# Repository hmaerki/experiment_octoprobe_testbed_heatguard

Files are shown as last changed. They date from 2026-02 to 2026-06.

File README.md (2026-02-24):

# experiment_octoprobe_testbed_heatguard
Use octoprobe to test the heatguard for vat pasteurization

## Punchy names for the subsystem

If you want a single, punchy name that sounds professional and captures the "guardian" nature of the device, here are a few proposals categorized by their "vibe":

The Technical Favorites
These sound like official components you would find in an industrial manual:

Thermostop: Clear, concise, and tells you exactly what happens when things go wrong.

Heatguard: Suggests a protective layer standing between the tank and a meltdown.

Safeterm: A portmanteau of "Safety" and "Thermal."

Sentitherm: Combines "Sentinel" (a guard) and "Thermal."

The "Action" Names
These focus on the emergency intervention aspect:

Interlock: The classic engineering term for a system that prevents operation unless specific safety conditions are met.

Cutout: Simple and direct; it describes the physical act of breaking the circuit.

Failsafe: Implies the system is designed to default to a safe state (off) upon error.

The Modern/Sleek Options
If you are naming this for a software module or a branded product:

Pyrowatch: Sounds vigilant and high-tech.

Calyx: (The protective outer part of a flower) — a bit more abstract, but sophisticated.

Vigilant: Short, evocative, and emphasizes the monitoring aspect.

## Punchy names for the application

* Industry	The Problem	The Punchy Name
* Aerospace	Engine overheating	AeroFailsafe
* Nuclear/Energy	Reactor/Boiler runaway	CoreWatch
* Home Automation	Smart water heaters	HomeSentry
* Cryogenics	Warming of liquid nitrogen	FrostGuard

## Industries

1. The Pharmaceutical Industry

In drug manufacturing, "stable" isn't good enough—it must be exact.

* The Application: Water is used in Jacketed Reactors to maintain precise environments for chemical synthesis and in Autoclaves for sterilization.
* The Precision: Often requires accuracy within $\pm 0.5$°C.
* The Risk: If the sensor drifts, the "active pharmaceutical ingredients" (APIs) can degrade, rendering a multi-million dollar batch useless or toxic.
* TPC Punchy Name: BatchGuard2.

2. Food & Beverage (Pasteurization)

Any process involving the "Kill Stage" for bacteria requires a TPC to ensure the temperature never dips too low or spikes too high.

* The Application: Flash Pasteurization of milk, juices, or beer.The Precision: Liquids must be held at a specific temperature (e.g., $72$°C) for a precise number of seconds.
* The Risk: Too low, and you risk a Salmonella outbreak; too high, and the product "cooks" or denatures, ruining the flavor.TPC Punchy Name: PureFlow3. Semiconductor & Electronics ManufacturingThe machines that make computer chips (Photolithography) require incredibly stable thermal environments.
* The Application: Deionized (DI) Water Heating for cleaning silicon wafers.
* The Precision: Thermal fluctuations can cause microscopic expansion or contraction of the wafers, leading to alignment errors in the nanometer range.
* The Risk: Total loss of "yield" (the number of working chips per wafer).
* TPC Punchy Name: NanoSentry

4. Textile & Chemical Dyeing

Color consistency in high-end textiles depends entirely on the temperature of the water bath.

* The Application: Industrial Dye Vats.
* The Precision: Dyes react differently at $79$°C than at $82$°C, causing "color banding."
* The Risk: "Metamerism" (where the color looks different under different lights) or uneven coloring across thousands of meters of fabric.
* TPC Punchy Name: HueLock

5. Modern District Heating (Smart Cities)

Centralized boilers that pump hot water to entire neighborhoods.

* The Application: Hydronic Balancing of large-scale heating loops.
* The Precision: Modern systems use "Predictive Temperature Control" to adjust water heat based on outdoor weather.
* The Risk: A sensor error could lead to "Scald Events" in residential taps or massive energy waste if the boiler over-fires.
* TPC Punchy Name: CitySentry

## Real world products

* https://www.cstainlessllc.com/files/pdfs/vat-pasteurizer-brochure.pdf
* https://www.ancoequipment.com/batch-pasteurizers
* https://pmc.ncbi.nlm.nih.gov/articles/PMC12026572/
  * https://pmc.ncbi.nlm.nih.gov/articles/PMC12026572/table/foods-14-01342-t001/
* https://kalt-ag.ch/en/cheese-vats/
* https://inoxmontagen.ch/produkte/kaesekessel-und-pasteurisatoren/pasteurisator-plevnik-alles-in-einem/
* https://inoxmontagen.ch/produkte/kaesekessel-und-pasteurisatoren/pasteurisatoren-pasteur-plevnik/
* https://www.gea.com/en/products/liquid-processing/pasteurizers/milk-pasteurizer/

## Diagrams about UHT

https://asutp.org/Tetra_Pak/Dairy-Processing-Handbook-Tetrapak.pdf

  * UHT treatment

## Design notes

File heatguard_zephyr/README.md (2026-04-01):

# devcontainer

```bash
west init .
west update --narrow --fetch-opt=--depth=1
west build -b rpi_pico heatguard_zephyr
```

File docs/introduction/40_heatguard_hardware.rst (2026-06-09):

Heatguard Hardware
===========================

:download:`Schematics v0.3 (Pdf) <../../kicad/heatguard_v0.3/production_v0.3/schematics_heatguard_v0.3.pdf>`.

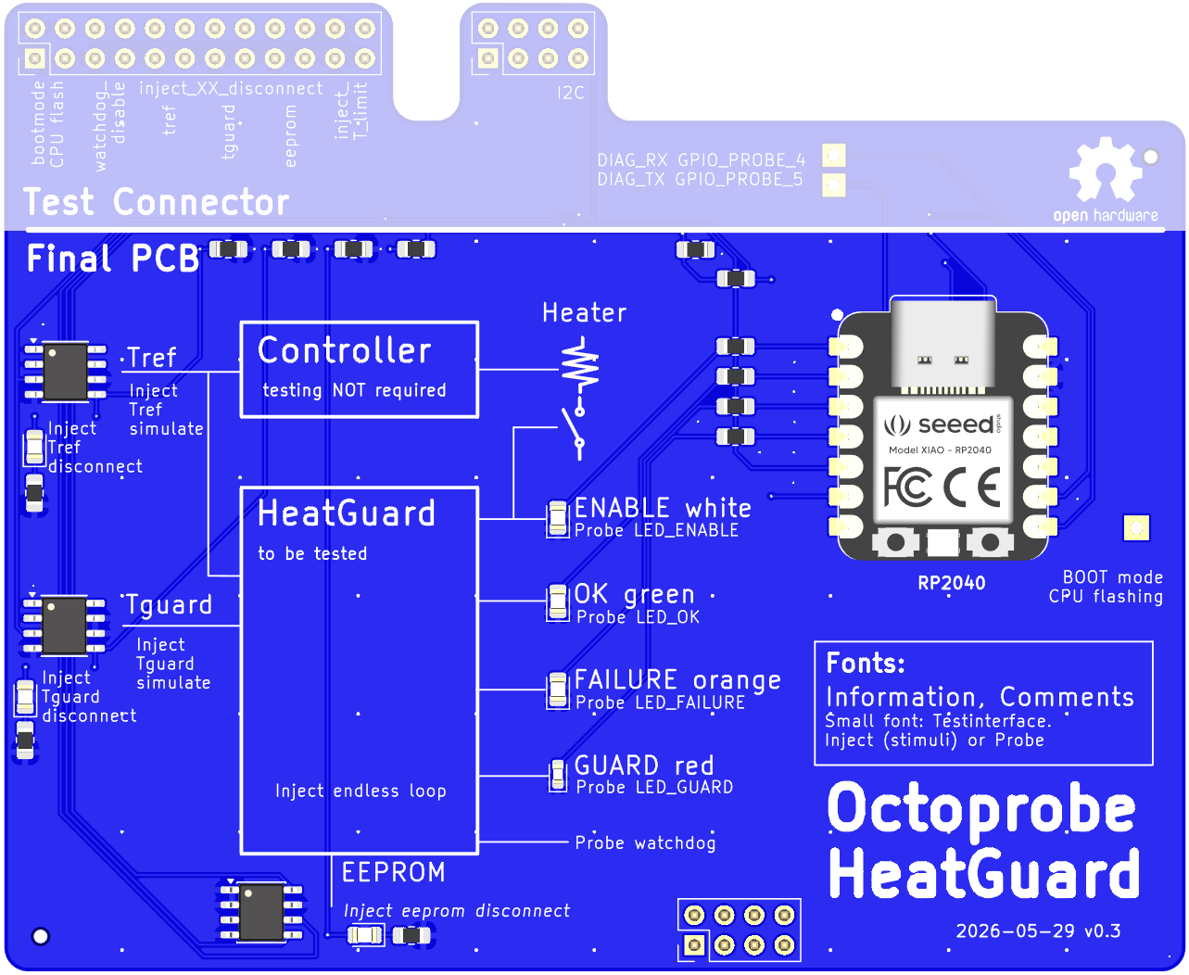
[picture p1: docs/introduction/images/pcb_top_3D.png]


To understand the hardware, just look at the silkscreen carefully. Note that I used a small fonts to describe what was added for the testinterface.

.. note:: 

  The implementation of the `Stimuly (inject)` and `Probes` only has very minimal impact on the `Final PCB`: We do not want to make the final PCB more expensive or bigger!

  The `Test Connector` would be typically implemented using flying probes or a solder pads as this requires minimal space on the PCB and no additional cost.

Assignements of the 8 pin testconnector and the relays
--------------------------------------------------------

.. list-table::
   :header-rows: 1

   * - Tentacle
     - DUT - heatguard
     - Signal
   * - relay 1
     - Boot button
     - Boot mode
   * - relay 2
     - pin 10, gpio 4
     - watchdog_disable
   * - relay 3
     - \-
     - inject_Tref_disconnect
   * - relay 4
     - \-
     - inject_Tguard_disconnect
   * - relay 5 
     - \-
     - inject_EEPROM_disconnect
   * - relay 6
     - pin 9, gpio 2
     - inject_T_limit (overwrite Tguard over temperature output)
   * - gpio 12
     - pin 5, gpio 6
     - SDA
   * - gpio 13
     - pin 6, gpio 7
     - SCL
   * - GPIO_PROBE_4
     - pin 8, gpio 1
     - DIAG_RX
   * - GPIO_PROBE_5
     - pin 7, gpio 0
     - DIAG_TX

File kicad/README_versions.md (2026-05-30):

# Octoprobe Heatguard

## History v0.2 -> v0.3

* PCB/Schematics: Now using relays in favor of GPIO
* PCB/Schematics: Rename stimuly -> stimulus
* PCB silkscreen: Open Hardware logo
* PCB silkscreen: Insert missing text `Controller` / `testing not required`
* PCB silkscreen: Switch GPIO_PROBE_4 and GPIO_PROBE_4
* PCB: XIAO rp2040: Replace SMD with THT

## History v0.1 -> v0.2

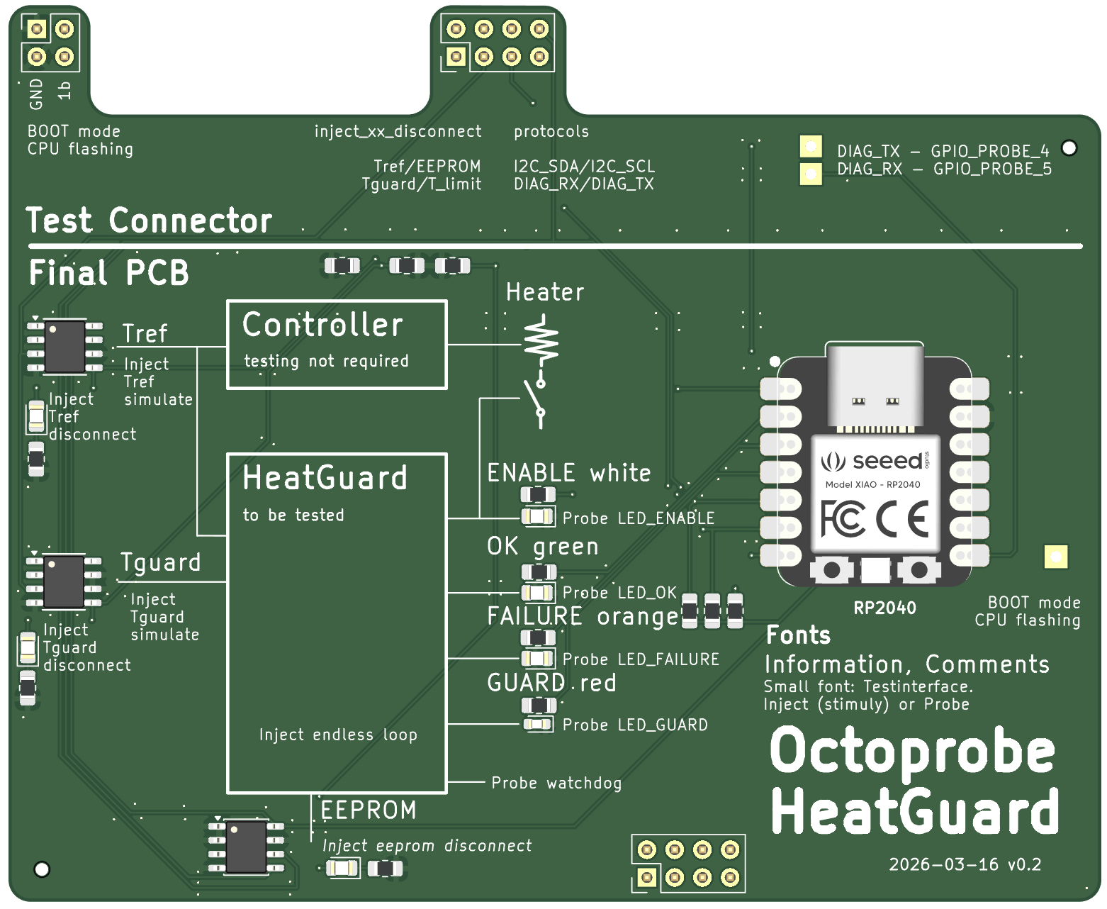
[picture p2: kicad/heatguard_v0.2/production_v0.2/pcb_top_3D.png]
tentacle


[schematics](heatguard_v0.2/production_v0.2/schematics_heatguard_v0.2.pdf)

* XIAO: Now smd (was on pins)
* Now connect to tentacle via soldered 2 row pin connectors
* while LEDs for inject Tref/Tguard/EEPROM

## History v0.1

tentacle

[schematics](heatguard_v0.1/production_v0.1/schematics_heatguard_v0.1.pdf)

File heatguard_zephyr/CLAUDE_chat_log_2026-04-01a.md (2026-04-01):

# Chat Log 2026-04-01a — Heatguard Zephyr Port

## Request 1: Add a Claude specification/hints file

Created `/CLAUDE.md` at the project root with hints covering:
- Project purpose (Octoprobe HIL test environment for heatguard)
- Python ≥ 3.12, `.venv/`, `uv pip install`
- Lint/type-check/test commands (ruff, mypy strict, pylint, pytest)
- Code style (ruff target py312, E501 disabled, mypy strict, PEP 561)
- Project layout (`src/`, `tests/`, `docs/`, `commissioning/`, `kicad/`, `heatguard_zephyr/`)
- Key conventions (PDM backend, octoprobe dependency, test markers)

## Request 2: Follow the instructions in `heatguard_zephyr/CLAUDE.md`

The file `heatguard_zephyr/CLAUDE.md` instructed:

> This folder contains a zephyr application which runs on a Raspberry Pi Pico.
> The program is already implemented in micropython, see `./main.py`.
> This program should now be rewritten in C/C++ to run on zephyr.
>
> Required Results:
> - Directory structure as used for a common zephyr application.
> - Script which compiles the sources into the firmware using `ghcr.io/zephyrproject-rtos/zephyr-build:main`.

### Files created

```
heatguard_zephyr/
  west.yml                     # West manifest (zephyr + hal_rpi_pico + picolibc)
  CMakeLists.txt               # Zephyr CMake build file
  prj.conf                     # Kconfig: GPIO, I2C, UART, WDT, float printf
  build.sh                     # Docker build script (zephyr-build:main)
  boards/
    rpi_pico.overlay           # DT overlay: I2C1 GPIO6/7, UART0 9600 baud
  src/
    main.c                     # Full C port of main.py
```

### Port details

- **State machine** — `INIT → OK → FAILURE / GUARD` with same thresholds:
  - 80 °C guard trigger
  - 3 °C diff failure trigger
  - 60 s guard recovery timeout
- **Diagnostic UART** — parses the same commands:
  - `stimulus heatguard.update_temperatures(temperature_Tguard_C=…, diff_C=…)`
  - `stimulus heatguard.sensor_failed("…")`
  - `inject timeover`
  - `inject endless_loop`
  - `ping` → `pong 'response to ping'`
- **I2C** — raw register reads for LM75B (11-bit temperature) and AT24C02 EEPROM
- **Boot cause** — Zephyr `hwinfo` API → `PWRON_RESET` / `WDT_RESET`
- **LEDs** — GPIO26-29 status LEDs, GPIO16/17/25 XIAO onboard (active-low)
- **Watchdog** — 3 s hardware WDT via Zephyr WDT API
- **Build** — `./build.sh` runs Docker, outputs `zephyr.uf2` + `zephyr.elf`

### Bug note

The Python `sensor_failed()` had `self.state == (self.STATE_INIT, self.STATE_GUARD)` which always evaluates `False` (comparing a string to a tuple). The C port uses the likely intended `state == STATE_INIT || state == STATE_GUARD`.

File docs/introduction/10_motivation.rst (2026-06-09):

Motivation
===========================

.. note:: 

  `testbed_heatguard` shows best practices of software testing with HIL (Hardware in the Loop).

  The hardware cost of the the `tentacle` PCB and the `heatguard` PCB are below EUR20. This makes it predestinated to learn about octoprobe and evaluate the concepts.

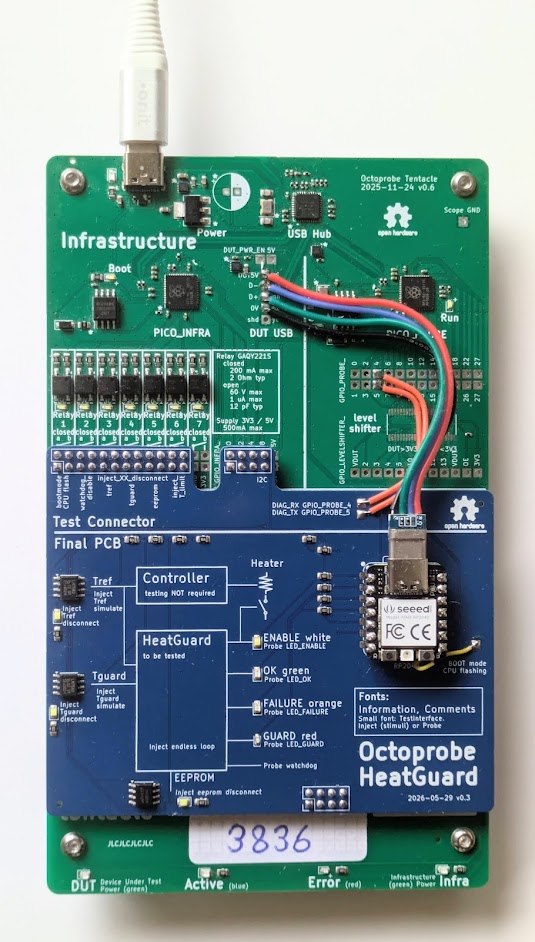
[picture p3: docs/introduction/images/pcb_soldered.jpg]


Szenario
----------

In a typical embedded project there are aspects which are difficult to test. In `testbed_headguard`:

* Errors on I2C
* High temperature
* Watchdog recovering crashed software

In `testbed_headguard` we concetrate on these difficult error cases as there is typically no way to test these condition in manual testing.

The product `headguard`
-------------------------

`heatguard` is an embedded device which is used to control temperature for vat pasteurization.



`heatguard` consists of two components
^^^^^^^^^^^^^^^^^^^^^^^^^^^^^^^^^^^^^^^^^^^^

* Controller: This is the software which controls the `Heater`. As engineers enhance and tune this code every day, manual testing is sufficient.
* HeatGuard: For safety, the `Heater` has to be switched on under certain conditions. The hardware and software has been developed many years ago. Nobody would notice if this logic starts failing. So we require:

  * The production software shall be tested on a final PCB (HIL).
  * A `Test Connecter` allows to inject errors and probe the state.
  * The tests should run fully automated controlled by CI/CD.
  * A developer should be able to reproduce the tests on his desk.

There are many ways how to build a testsystem. `testbed_headguard` should show best practices:

  * How to intercept hardware (I2C errors, I2C simulation)
  * How to use a diag-uart-interface to probe the state or inject stimuy.
  * How to automate firmware flashing and software download.

.. note:: 

    We do NOT want to test the software on a simulated hardware.
    
    It is required to use the final PCB as this ensures that the real components (temperature sensor, CPU, watchdog) are used.

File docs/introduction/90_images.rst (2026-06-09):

Images
===========================



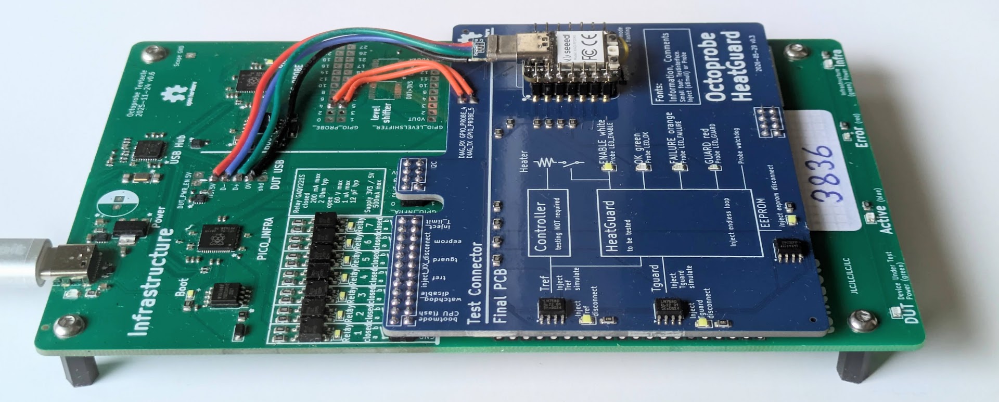
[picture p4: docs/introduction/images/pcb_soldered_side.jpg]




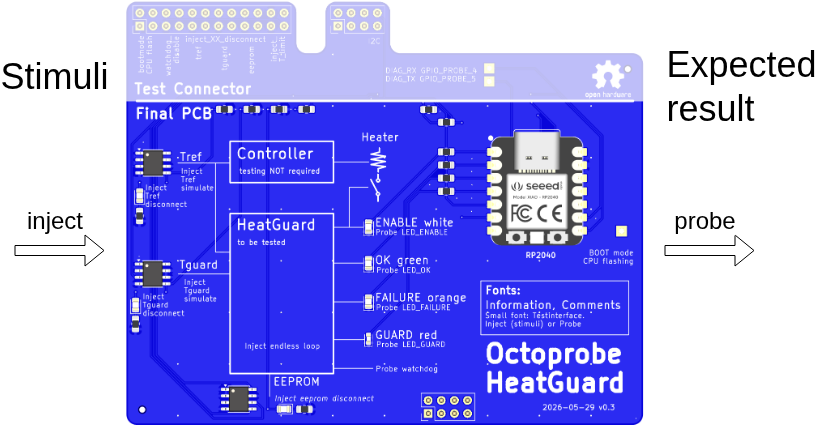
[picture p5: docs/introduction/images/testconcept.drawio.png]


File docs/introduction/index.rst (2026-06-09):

Introduction
============



.. toctree::
   :glob:
   :maxdepth: 4

   **

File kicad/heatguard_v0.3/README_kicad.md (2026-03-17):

# Plugins used

* https://github.com/bennymeg/JLC-Plugin-for-KiCad

  JLC PCB Plug-in for KiCad

  Fill Symbol Field `JLC Part`

* kicad-action-scripts

  ViaStiching, https://github.com/jsreynaud/kicad-action-scripts

## Production

### Increment version number

Update in all sheets (`*.kicad_*`)

`(date "2025-09-02")`

`(rev "0.5")`

### In schematics - final check

Menu `Inspect -> Electrical Rule Chacker`, button `Run ERC`, No violatons

### In pcb - ViaStiching

* remove

  Select one via (which will select a group) and delete

* stich

  PCB -> Toolbar -> Via Stitching Generator

  | Parameter | Value |
  | - | - |
  | Via copper size | 0.5 |
  | Via drill size | 0.3 |
  | Via clearance | 0.15 |
  | Via grid | 10.0 |
  | Net name | GND |
  | Pattern | Rectangular |
  | Checkboxes | Uncheck |

### In pcb - final check and final commit

Menu `Tools -> Cleanup Tracks & Vias`, select all,  `Build Changes`, No violatons

Menu `Inspect -> Design Rules Checker`, check `Refill all zones`, button `Run DRC . No errors, no warnings.

Delete all files in directory `production`.

Icon `Fabricaton Toolkit`, Options empty, check `Apply automatic translatons`, check `Exluce DNP components`.

Rename production folder and add version number

### Print schematics

Schematics, Menu `File -> Print`, check 'Print drawing sheet - Color`, `Print`, `All Pages`, `Print to File`.

Move `~/Documents/output.pdf` to `kicad/heatguard_v0.1/production_v0.1/schematics_heatguard_v0.1.pdf`

### Upload to JLCPCB

Tooling holes: `Added by Customer`

Accept these warnings:
```
The below parts won't be assembled due to data missing.
J2,J3,J4,J5,J6,J7,U4 designators don't exist in the BOM file.
```
BOM

 * Verify that the correct values, specially C and R, have been choosen.
 * ...

Manual correction

 * ...

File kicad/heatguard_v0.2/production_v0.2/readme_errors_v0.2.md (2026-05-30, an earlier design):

# Errors on v0.2

* DONE Schematics: Why do we use GPIO for inject_xx. Relays would have a LED and a op interface!

* DONE PCB silkscreen: Open Hardware logo
* DONE Rename stimuly -> stimulus

* DONE Text missing: `Controller` / `testing not required`
* DONE `diag_tx`/`diag_rx` is too close below USB connector
* DONE Footprint XIAO: Missing trough hole to allow soldering with pins

* DONE PCB silkscreen: Switch GPIO_PROBE_4 and GPIO_PROBE_4

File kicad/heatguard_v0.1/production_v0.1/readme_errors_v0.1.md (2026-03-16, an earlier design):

# Errors on v0.1

* Allow XIAO to be soldered directly to the PCB

* 4 pins to mount the board are much too weak

* Schematics:

  * Now: 0x4D (simulation)
  * Better: 0x4D (disconnect)

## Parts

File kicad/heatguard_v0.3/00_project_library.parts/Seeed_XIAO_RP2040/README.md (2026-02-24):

https://www.seeedstudio.com/blog/2020/04/23/use-seeeduino-xiao-in-kicad-pcb-design-like-a-components

https://wiki.seeedstudio.com/XIAO-RP2040/
https://files.seeedstudio.com/wiki/XIAO-RP2040/res/Seeed-Studio-XIAO-RP2040-v1.3.pdf

XIAO_Series_Footprints.zip
XIAO_Series_SCH_Symbols.zip
seeed-studio-xiao-rp2040-3d-model.zip

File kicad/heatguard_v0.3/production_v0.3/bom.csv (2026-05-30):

Designator | Footprint | Quantity | Value | LCSC Part #
D1 | 0805 | 1 | LED GREEN | C2297
D10, D11, D12, D4 | 0805 | 4 | LED WHITE | C34499
D2 | 0805 | 1 | LED ORANGE | C2296
D3 | 0603 | 1 | LED RED | C2286
R1, R11, R12, R13, R2, R3, R4 | 0805 | 7 | 2k2
R10, R5, R6, R7, R8, R9 | 0805 | 6 | 4k7
U1, U2 | SOIC-8_3.9x4.9mm_P1.27mm | 2 | LM75B
U3 | SOIC-8_3.9x4.9mm_P1.27mm | 1 | M24C02-FMN
U4 | XIAO-RP2040-DIP | 1 | XIAO-RP2040-DIP

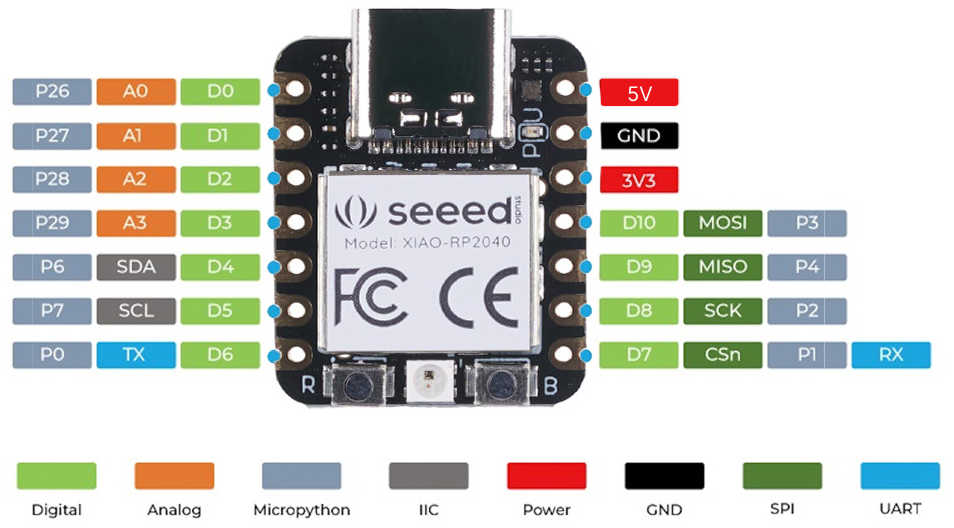
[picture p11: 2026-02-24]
kicad/heatguard_v0.3/00_project_library.parts/Seeed_XIAO_RP2040/doc/xinpin.jpg

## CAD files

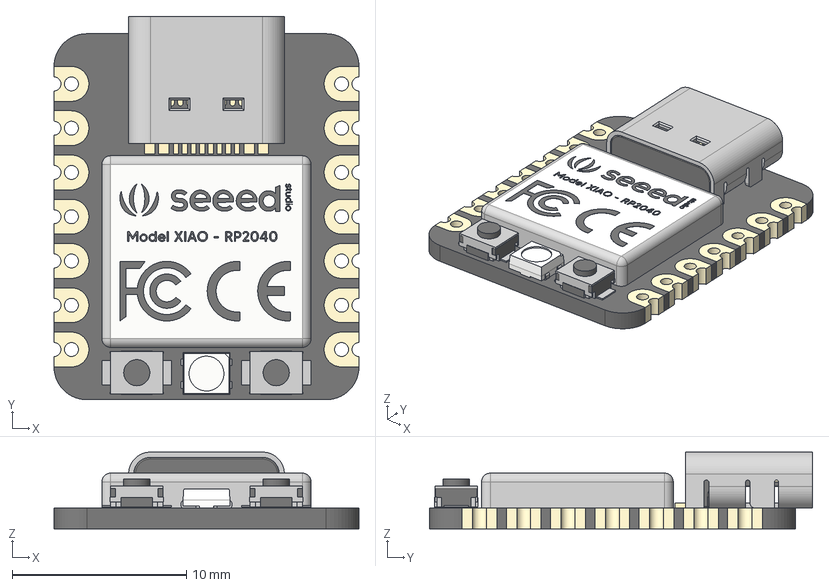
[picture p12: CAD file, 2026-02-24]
kicad/heatguard_v0.3/00_project_library.parts/Seeed_XIAO_RP2040/Seeed-Studio-XIAO-RP2040-v26.step
17.5 x 22.0 x 4.40 mm
type-c v2
smd_button v3
DOUT
DIN
VSS
VDD
smd_button v3(Mirror)

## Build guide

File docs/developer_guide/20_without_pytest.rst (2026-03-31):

Run heatguard without pytest
==============================

The commands require only `octoprobe` - `testbed_heatguard` is not used.

Show connected tentacles

.. code-block:: bash

    op query

Power on DUT, copy main.py and show output

.. code-block:: bash

    op power --on dut

    # Copy main.py and restart main.py: Blue led starts blinking
    mpremote a1 cp src/testbed_heatguard/mp_dut_main.py :main.py

    # Observe output
    mpremote a1

Run main.py directly from mpremote

.. code-block:: bash

    op power --on dut

    # Remove main.py and restart: blue led is off!
    mpremote a1 rm :main.py
    mpremote a1 reset

    # Run main from memory and observe output
    mpremote a1 run src/testbed_heatguard/mp_dut_main.py

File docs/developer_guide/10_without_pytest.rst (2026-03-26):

Run heatguard without pytest
==============================

The commands require only `octoprobe` - `testbed_heatguard` is not used.

Show connected tentacles

.. code-block:: bash

    op query

Power on DUT, copy main.py and show output

.. code-block:: bash

    op power --on dut

    # Copy main.py and restart main.py: Blue led starts blinking
    mpremote a1 cp src/testbed_heatguard/mp_dut_main.py :main.py

    # Observe output
    mpremote a1

Run main.py directly from mpremote

.. code-block:: bash

    op power --on dut

    # Remove main.py and restart: blue led is off!
    mpremote a1 rm :main.py
    mpremote a1 reset

    # Run main from memory and observe output
    mpremote a1 run src/testbed_heatguard/mp_dut_main.py

Power on DUT but in programming mode and flash micropython

.. code-block:: bash

    op power --off dut; op power --on relay1; sleep 1;op power --on dut; sleep 1; op power --off relay1

    cd /media/$USER/RPI-RP2
    wget https://micropython.org/resources/firmware/RPI_PICO-20251209-v1.27.0.uf2

This corresponds to src/testbed_heatguard/util_ctx.py: `tentacle.flash_dut()`.

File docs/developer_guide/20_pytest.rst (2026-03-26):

Run pytest on heatguard
==============================

Run pytest

.. code-block:: bash

    pytest

    =============================================================================================== test session starts ===============================================================================================
    collected 13 items                                                                                                                                                                                                

    tests/test_conditions_FAILURE.py ......                                                                                                                                                                     [ 46%]
    tests/test_conditions_GUARD.py ..                                                                                                                                                                           [ 61%]
    tests/test_conditions_OK.py .                                                                                                                                                                               [ 69%]
    tests/test_lowlevel.py ....                                                                                                                                                                                 [100%]

Run pytest with text output and verbose on a specific test

.. code-block:: bash

    pytest -s -v tests/test_conditions_FAILURE.py::test_Tdiff_high

    =============================================================================================== test session starts ===============================================================================================

    tests/test_conditions_FAILURE.py::test_Tdiff_high INFO     TEST SETUP  0s tests/test_conditions_FAILURE.py::test_Tdiff_high
    INFO     Tentacle DUT 4b35-MCU_HEADGUARD: Version installed: RPI_PICO;3.4.0; MicroPython v1.27.0 on 2025-12-09;Raspberry Pi Pico with RP2040
    INFO     Tentacle DUT 4b35-MCU_HEADGUARD: Firmware is already installed
    INFO     [COLOR_TEST_STATEMENT]conftest.py:129 load_mp_infra()  
    INFO     [COLOR_INFO]TEST BEGIN  1s tests/test_conditions_FAILURE.py::test_Tdiff_high
    INFO     [COLOR_TEST_STATEMENT]conftest.py:46 set_power_dut(on=True, start_dut_main=True)  
    ...
    INFO     [COLOR_TEST_STATEMENT]test_conditions_FAILURE.py:23 diag_infra_waitfor(expected_line='probe state OK True', timeout_s=2.0, drain=True)  
    INFO     [COLOR_INFO]diag_infra_waitfor(expected_line='probe state OK True')
    INFO     [COLOR_TEST_STATEMENT]tentacle_spec.py:289 diag_infra_get_lines(drain=True)  
    PASSEDINFO     [COLOR_SUCCESS]TEST TEARDOWN  5s tests/test_conditions_FAILURE.py::test_Tdiff_high
    INFO     TEST END  5s tests/test_conditions_FAILURE.py::test_Tdiff_high

    ================================================================================================ 1 passed in 4.70s ================================================================================================

Run pytest and observer the DUT output of main.py
^^^^^^^^^^^^^^^^^^^^^^^^^^^^^^^^^^^^^^^^^^^^^^^^^

Set breakpoint in conftest.py just after line `logger.info(f"DUT may be connected: mpremote connect {tty}")`.

Let pytest run into the breakpoint.

.. code-block:: bash

    mpremote a1

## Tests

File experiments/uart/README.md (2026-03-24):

# UART

These examples demonstrates how the PICO_INFRA uart reader survives a repl.

PICO_INFRA is a uart reader

DUT is a uart writer

## Test

Run a test so that PICO_INFRA and DUT have the micropython code loaded

DUT

```
mpremote a1 exec 'import rp2; rp2.SKIP_MAIN = True; import main; main.uart.ping_forever()'
```

PICO_INFRA

```
mpremote a1 exec 'uart.get_lines()'
```

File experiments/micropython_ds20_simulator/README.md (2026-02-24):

# DS18B20 Sensor Simulator for Raspberry Pi Pico

A complete MicroPython simulator for the Analog Devices DS18B20 temperature sensor, implementing the authentic 1-Wire protocol as specified in the datasheet.

## Features

- **Full 1-Wire Protocol Support**: ROM search, matching, temperature conversion
- **Accurate Sensor Simulation**: Scratchpad memory, CRC-8 validation, configurable resolution
- **Multiple Sensors**: Support for multiple DS18B20 sensors on the same 1-Wire bus
- **Configurable Resolution**: 9-12 bit temperature resolution (0.5°C to 0.0625°C)
- **Alarm Thresholds**: Programmable TH (high) and TL (low) temperature thresholds
- **Realistic Behavior**: Conversion times based on resolution (93.75ms to 750ms)
- **MicroPython Compatible**: Pure MicroPython, no external library dependencies
- **Educational**: Learn 1-Wire protocol and DS18B20 operation

## Hardware Setup

### GPIO Pin Configuration (Raspberry Pi Pico)

| Purpose | Pin | GPIO |
|---|-----|---|
| 1-Wire Data Line | 0 | GPIO0 |
| Ground | N/A | GND |

### Wiring Diagram

```
Pico GPIO0 ----[4.7k]---- 3.3V
           |
        DS18B20 (DQ pin)
           |
        GND
```

Note: The 4.7k pull-up resistor is required for 1-Wire operation (open-drain protocol).

## Files

- **main.py** - Core simulator implementation
  - `DS18B20Sensor` - Single sensor simulation with full 1-Wire command support
  - `OneWireSimulator` - 1-Wire bus management for multiple sensors
  - Comprehensive 1-Wire command handling
  - CRC-8 calculation and validation
  - Realistic sensor behavior

- **example_usage.py** - Practical usage examples
  - Single sensor reading
  - Multiple sensor discovery and reading
  - Alarm threshold configuration
  - Resolution settings comparison
  - Continuous monitoring
  - Real hardware code examples

- **README.md** - This file

## Quick Start

### Basic Temperature Reading

```python
from main import DS18B20Sensor, OneWireSimulator, CONVERT_TEMP, READ_SCRATCHPAD
import time

# Create simulator
bus = OneWireSimulator()
sensor = DS18B20Sensor(current_temp=25.0)
bus.add_sensor(sensor)

# Use skip ROM for single sensor
bus.skip_rom()

# Convert temperature
bus.execute_command(CONVERT_TEMP)
time.sleep(0.8)  # Wait for conversion (12-bit mode)

# Read result
scratchpad = bus.execute_command(READ_SCRATCHPAD)
temp = sensor.get_temperature_celsius()
print("Temperature: {:.4f}C".format(temp))
```

### Multiple Sensors with Discovery

```python
from main import DS18B20Sensor, OneWireSimulator, CONVERT_TEMP, READ_SCRATCHPAD
import time

# Create bus with multiple sensors
bus = OneWireSimulator()
bus.add_sensor(DS18B20Sensor(current_temp=20.0))
bus.add_sensor(DS18B20Sensor(current_temp=25.0))

# Discover all devices
roms = bus.search_rom()

# Read from each sensor
for rom in roms:
    bus.reset()
    bus.match_rom(rom)
    bus.execute_command(CONVERT_TEMP)
    time.sleep(0.8)
    scratchpad = bus.execute_command(READ_SCRATCHPAD)
    # Extract temperature from RTC
    temp = (scratchpad[1] << 8 | scratchpad[0]) / 16.0
    print("Temperature: {:.4f}C".format(temp))
```

## 1-Wire Commands

All commands are implemented according to the DS18B20 datasheet:

### ROM Commands (for device addressing)
- `0xF0` - **SEARCH_ROM** - ROM search (device discovery)
- `0x33` - **READ_ROM** - Read ROM code (single device)
- `0x55` - **MATCH_ROM** - Select device by ROM code
- `0xCC` - **SKIP_ROM** - Select all devices (single device on bus)

### Memory & Sensor Commands
- `0x44` - **CONVERT_TEMP** - Initiate temperature conversion
- `0xBE` - **READ_SCRATCHPAD** - Read sensor data (9 bytes)
- `0x4E` - **WRITE_SCRATCHPAD** - Write TH, TL, CONFIG registers
- `0x48` - **COPY_SCRATCHPAD** - Write scratchpad to EEPROM
- `0xB8` - **RECALL_E2** - Copy EEPROM to scratchpad
- `0xB4` - **READ_POWER_SUPPLY** - Check power mode

## Scratchpad Memory Map

| Byte | Name | R/W | Description |
|---|---|-----|---|
| 0 | TEMP_LSB | R | Temperature LSB |
| 1 | TEMP_MSB | R | Temperature MSB |
| 2 | TH | R/W | High temperature alarm threshold |
| 3 | TL | R/W | Low temperature alarm threshold |
| 4 | CONFIG | R/W | Configuration register |
| 5-7 | Reserved | R | Reserved (always 0xFF, 0x00, 0x00) |
| 8 | CRC | R | CRC-8 of bytes 0-7 |

### Temperature Encoding

Temperature is stored as a 16-bit signed value:
- **Format**: [MSB] = sign and integer part, [LSB] = fractional part
- **Resolution**: LSB = 0.0625°C in 12-bit mode
- **Formula**: T = (MSB << 8 | LSB) / 16.0

**Examples**:
- 25°C   = 0x0190 (0x01, 0x90)
- -10°C  = 0xFFF6 (0xFF, 0xF6)

### Configuration Register (Byte 4)

```
Bit 7-6: Resolution
  00 = 9-bit  (0.5°C)      - 93.75ms conversion
  01 = 10-bit (0.25°C)     - 187.5ms conversion
  10 = 11-bit (0.125°C)    - 375ms conversion
  11 = 12-bit (0.0625°C)   - 750ms conversion [default]

Bit 5-4: Reserved (always 0)
Bit 3-0: Reserved (always 0)
```

## Temperature Specifications

| Parameter | Value |
|---|---|
| Operating Range | -55°C to +125°C |
| Accuracy | ±0.5°C |
| Temp Coefficient | 0.0625°C/LSB |
| Conversion Time (9-bit) | 93.75ms |
| Conversion Time (10-bit) | 187.5ms |
| Conversion Time (11-bit) | 375ms |
| Conversion Time (12-bit) | 750ms |

## Usage Patterns

### Pattern 1: Single Sensor (SKIP_ROM)
```python
bus.skip_rom()
bus.execute_command(CONVERT_TEMP)
time.sleep(0.75)
scratchpad = bus.execute_command(READ_SCRATCHPAD)
```

Use when only one sensor is on the bus - saves time by skipping ROM addressing.

### Pattern 2: Multiple Sensors (MATCH_ROM)
```python
for rom in bus.search_rom():
    bus.reset()
    bus.match_rom(rom)
    bus.execute_command(CONVERT_TEMP)
    time.sleep(0.75)
    scratchpad = bus.execute_command(READ_SCRATCHPAD)
```

Use when multiple sensors are on the bus - discover all devices first, then address each individually.

### Pattern 3: Configure Alarms
```python
bus.match_rom(rom)
# TH=28°C, TL=20°C, 12-bit resolution
bus.execute_command(WRITE_SCRATCHPAD, bytes([28, 20, 0x7F]))
# Optionally copy to EEPROM
bus.execute_command(COPY_SCRATCHPAD)
```

Set temperature thresholds for alarm functionality.

## API Reference

### DS18B20Sensor Class

```python
sensor = DS18B20Sensor(rom_code=None, current_temp=20.0)

# Set simulated temperature
sensor.set_temperature(25.5)

# Get current temperature reading
temp = sensor.get_temperature_celsius()

# Get resolution in bits
bits = sensor.get_resolution_bits()  # Returns 9, 10, 11, or 12

# Access scratchpad directly
sensor.scratchpad.config = 0x7F
sensor.scratchpad.th = 28
sensor.scratchpad.tl = 20
```

### OneWireSimulator Class

```python
bus = OneWireSimulator()

# Add sensors
bus.add_sensor(sensor1)
bus.add_sensor(sensor2)

# ROM operations
roms = bus.search_rom()
bus.match_rom(rom)
bus.skip_rom()
bus.reset()

# Execute commands
result = bus.execute_command(CONVERT_TEMP)
scratchpad = bus.execute_command(READ_SCRATCHPAD)
bus.execute_command(WRITE_SCRATCHPAD, bytes([th, tl, config]))
```

## Constants

```python
# GPIO Pins
GPIO_ONEWIRE_1 = 0      # Primary 1-Wire sensor
GPIO_ONEWIRE_2 = 1      # Secondary 1-Wire sensor (optional)

# 1-Wire Timing (microseconds)
ONEWIRE_RESET_TIME = 480
ONEWIRE_PRESENCE_TIME = 60
ONEWIRE_BIT_TIME = 60

# Command Codes
CONVERT_TEMP = 0x44
READ_SCRATCHPAD = 0xBE
WRITE_SCRATCHPAD = 0x4E
# ... etc

# Resolution Bits
RES_9BIT = 0b00
RES_10BIT = 0b01
RES_11BIT = 0b10
RES_12BIT = 0b11
```

## Testing

Run the main simulator:
```bash
python3 main.py          # CPython (for testing)
micropython main.py      # On Raspberry Pi Pico
```

Run usage examples:
```bash
python3 example_usage.py
```

## Real Hardware Integration

To use with real DS18B20 sensors on a Raspberry Pi Pico:

```python
import onewire
import ds18x20
import machine
import time

# Create 1-Wire bus
ow = onewire.OneWire(machine.Pin(0))

# Create DS18X20 object
ds = ds18x20.DS18X20(ow)

# Scan for devices
roms = ds.scan()

# Convert and read temperature
ds.convert_temp()
time.sleep(0.8)
for rom in roms:
    temp = ds.read_temp(rom)
    print("Temperature: {:.4f}C".format(temp))
```

## References

- [DS18B20 Datasheet](https://www.analog.com/media/en/technical-documentation/data-sheets/ds18b20.pdf) - Official Analog Devices documentation
- [1-Wire Protocol](https://en.wikipedia.org/wiki/1-Wire) - Wikipedia overview
- [Raspberry Pi Pico Datasheet](https://datasheets.raspberrypi.com/pico/pico-datasheet.pdf)
- MicroPython Documentation: `onewire` and `ds18x20` libraries

## License

See LICENSE file in workspace

## Notes

- This simulator is designed for testing and educational purposes
- Timing is simulated and not cycle-accurate; use for logic validation
- For hardware timing-critical applications, use real 1-Wire library
- ROM codes are randomly generated; set specific codes for deterministic testing
- Scratchpad CRC is calculated automatically on reads

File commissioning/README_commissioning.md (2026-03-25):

## Test XIAO

```bash
op power --on dut
```

```bash
op power --off dut; op power --on relay1; sleep 1;op power --on dut; sleep 1; op power --off relay1

wget https://micropython.org/resources/firmware/RPI_PICO-20251209-v1.27.0.uf2
```

* LED

```bash
mpremote a1 run test_leds.py
```

* UART DUT->PICO_INFRA

```bash
mpremote a0 run uart_PICO_INFRA.py
mpremote a1 run uart_dut.py
```

* I2C

```bash
mpremote a0 run lm75b_target.py 
mpremote a1 run lm75b_controller.py 
```

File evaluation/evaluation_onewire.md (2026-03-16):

# DS20

https://www.analog.com/media/en/technical-documentation/data-sheets/ds18b20.pdf

https://github.com/octoprobe/testbed_heatguard/blob/main/tests/test_simple.py#L91-L137

1Wire Temperature Sensor DS18B20 TO-92
  https://www.aliexpress.com/item/1005008977601125.html

https://gist.github.com/MarcosYonamine963/cc4d9b7d80dc94b34ad8e0d4abeb64e3

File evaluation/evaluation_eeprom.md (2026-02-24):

Simulated EEPROM

AT24CXX

* I2CTarget
* https://github.com/micropython/micropython/blob/master/tests/extmod_hardware/machine_i2c_target.py

I2C EEPROM AT24C08
  https://www.aliexpress.com/item/1005005344566156.html (old)
  https://www.aliexpress.com/item/1005007083692220.html

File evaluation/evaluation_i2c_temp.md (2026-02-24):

https://www.ti.com/product/LM75B

https://ae01.alicdn.com/kf/S34f70d0740d6429297afdf582dc8667dF.jpg
https://www.aliexpress.com/item/1005006459143994.html

https://jlcpcb.com/partdetail/NXPSemicon-LM75BD118/C34565

https://www.nxp.com/docs/en/data-sheet/LM75B.pdf
https://www.ti.com/product/LM75B
https://www.ti.com/lit/ds/symlink/lm75b.pdf

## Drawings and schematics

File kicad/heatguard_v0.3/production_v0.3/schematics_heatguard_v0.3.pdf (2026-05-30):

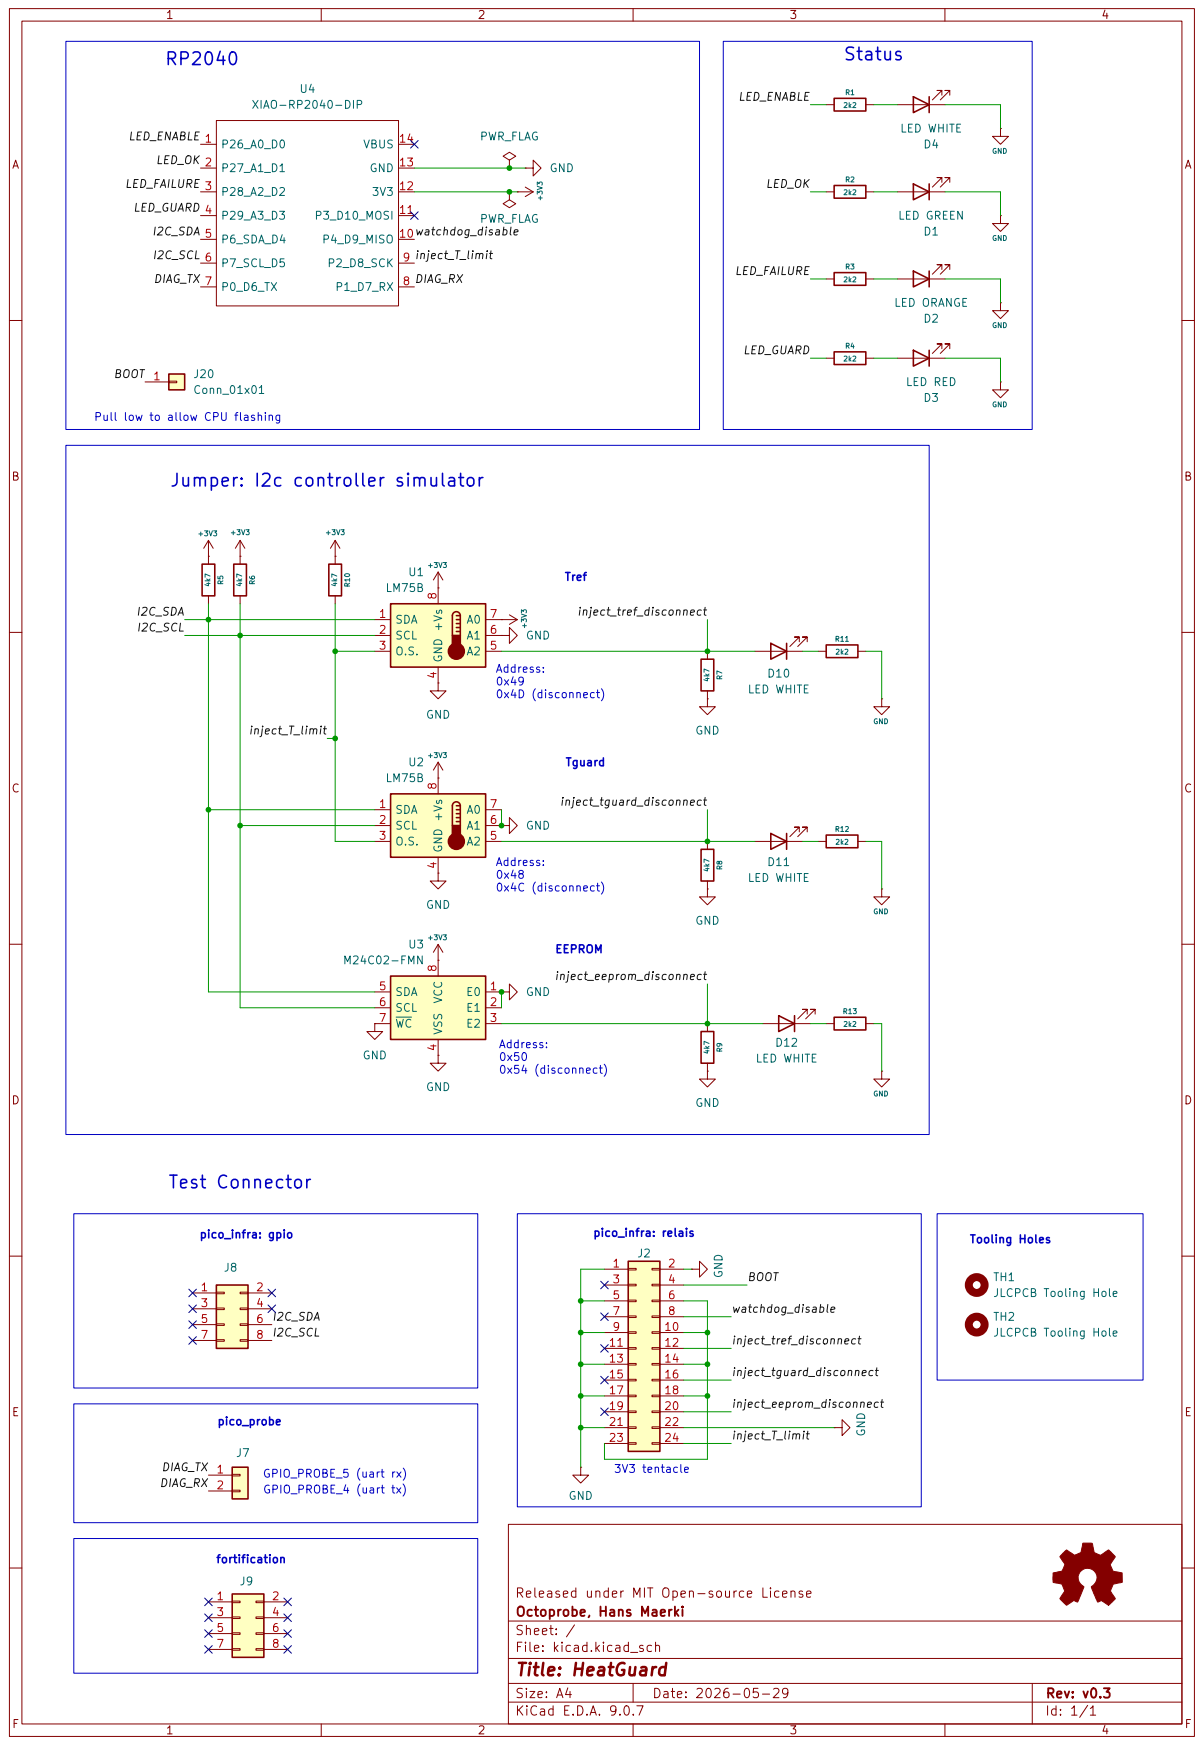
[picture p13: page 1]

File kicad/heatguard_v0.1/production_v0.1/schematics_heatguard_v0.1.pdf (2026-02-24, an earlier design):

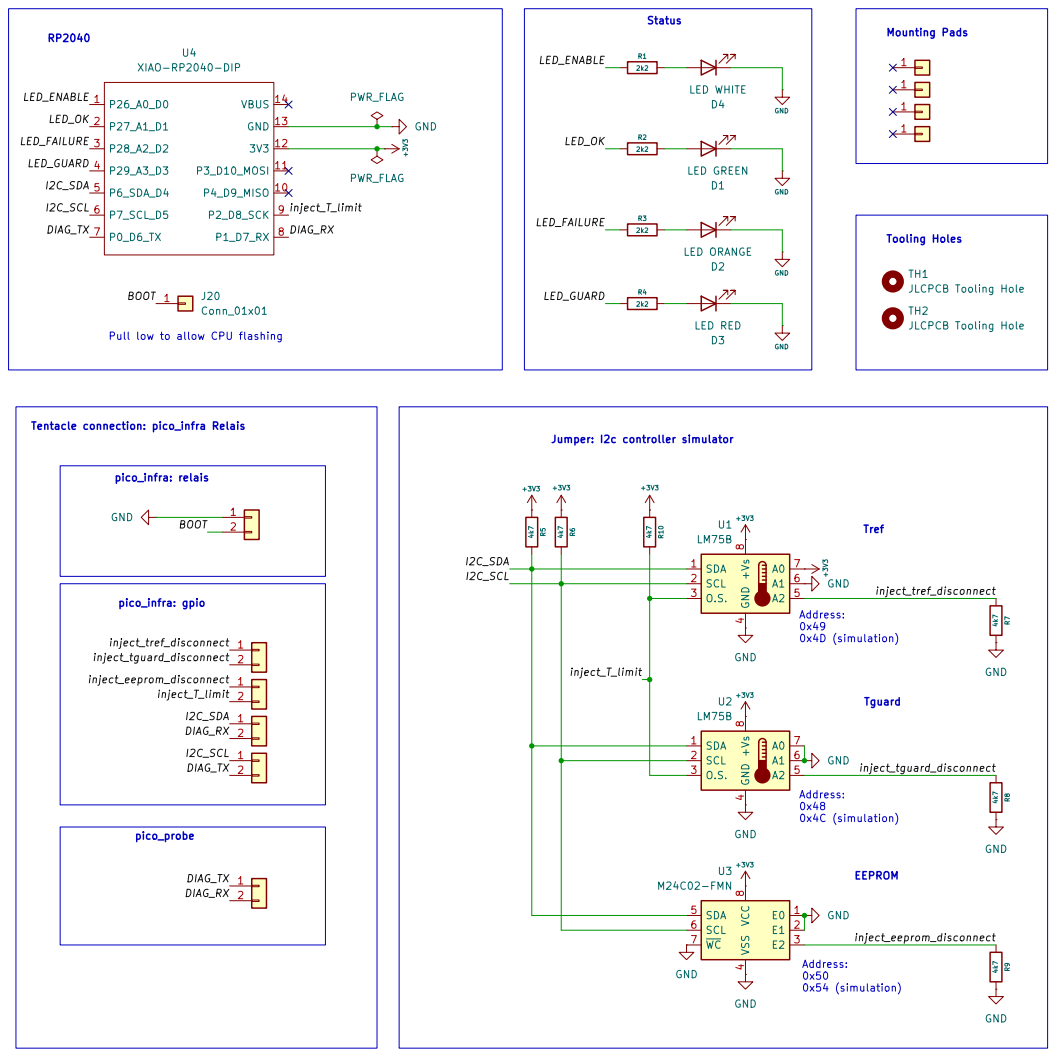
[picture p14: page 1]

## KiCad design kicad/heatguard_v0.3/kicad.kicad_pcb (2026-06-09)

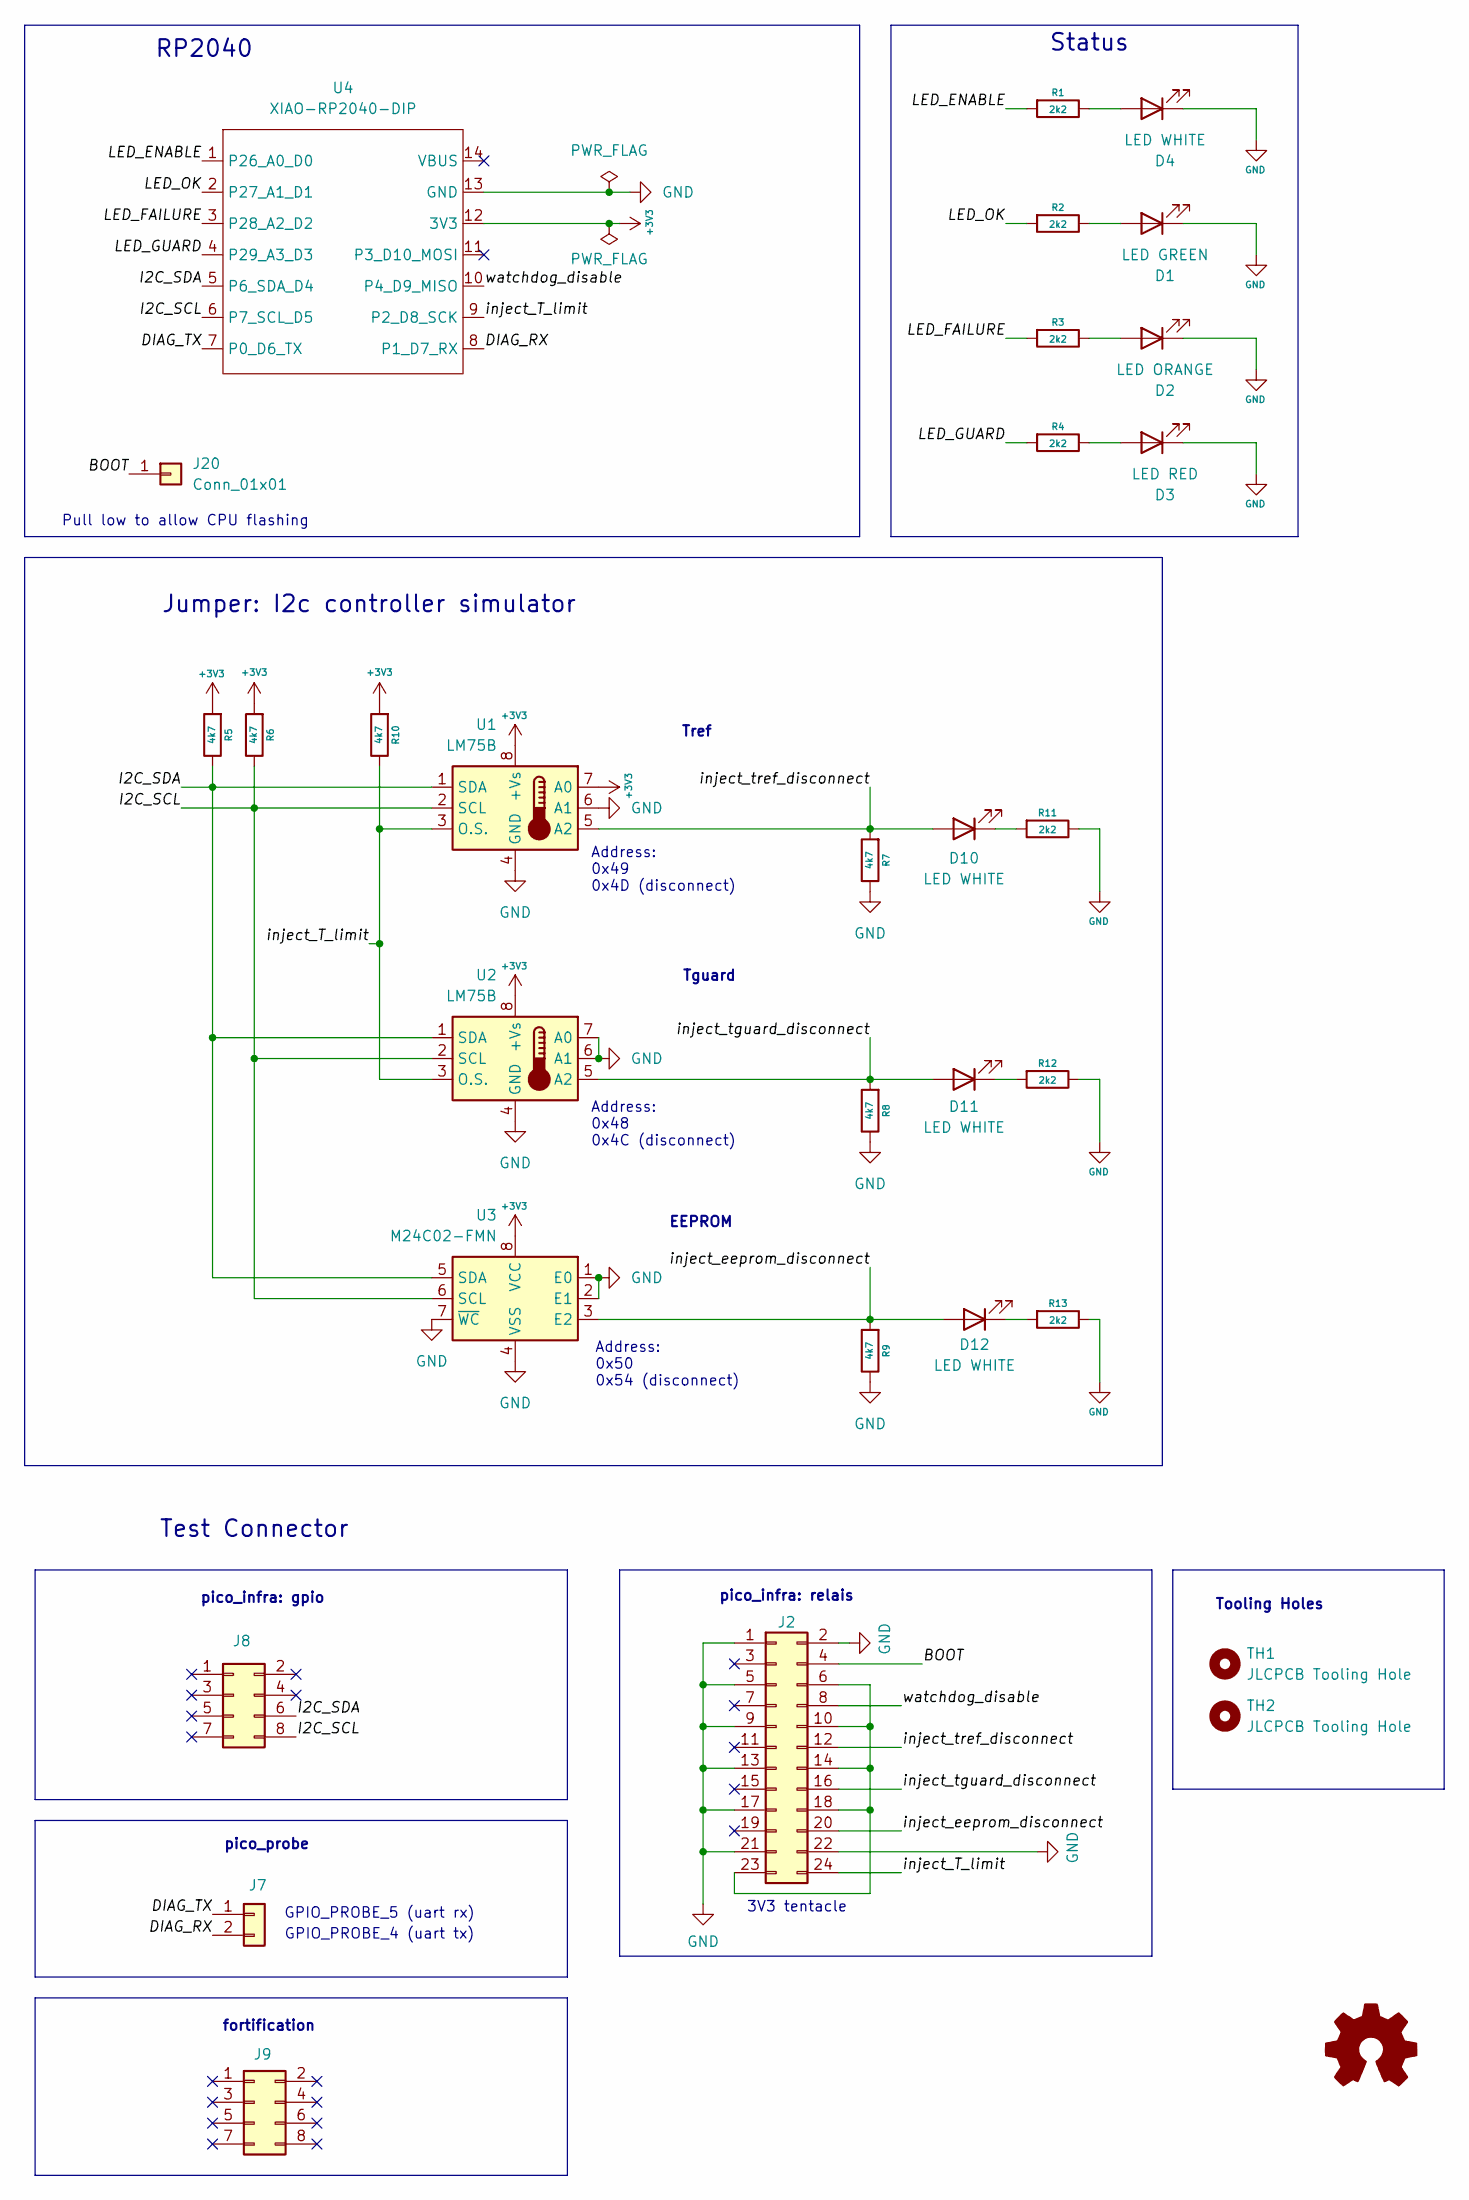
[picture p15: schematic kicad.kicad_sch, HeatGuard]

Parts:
D1: LED GREEN; LED_0805_2012Metric; JLC C2297
D2: LED ORANGE; LED_0805_2012Metric; JLC C2296
D3: LED RED; LED_0603_1608Metric; JLC C2286
D4, D10, D11, D12: LED WHITE; LED_0805_2012Metric; JLC C34499
J2: Conn_02x12_Odd_Even; PinHeader_2x12_P2.54mm_Vertical_back
J7: Conn_01x12; PinSocket_1x2_P2.54mm_Vertical_squarepad
J8, J9: Conn_02x04_Odd_Even; PinHeader_2x04_P2.54mm_Vertical_back
J20: Conn_01x01; octoprobe_breakout_PB
Logo_open_hardware101: Logo_Open_Hardware_Small; OSHW-Logo2_9.8x8mm_SilkScreen
R1, R2, R3, R4, R11, R12, R13: 2k2; R_0805_2012Metric_Pad1.20x1.40mm_HandSolder
R5, R6, R7, R8, R9, R10: 4k7; R_0805_2012Metric_Pad1.20x1.40mm_HandSolder
TH1, TH2: JLCPCB Tooling Hole; JLCPCB_ToolingHole
U1, U2: LM75B; SOIC-8_3.9x4.9mm_P1.27mm; JLCPCB C114502
U3: M24C02-FMN; SOIC-8_3.9x4.9mm_P1.27mm; JLCPCB C114502
U4: XIAO-RP2040-DIP

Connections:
+3V3: R5.2, R6.2, R10.2, U1.7 (A0), U1.8 (+Vs), U2.8 (+Vs), U3.8 (VCC), U4.12 (3V3)
/BOOT: J2.4, J20.1
/DIAG_RX: J7.2, U4.8 (P1_D7_RX)
/DIAG_TX: J7.1, U4.7 (P0_D6_TX)
/I2C_SCL: J8.8, R6.1, U1.2 (SCL), U2.2 (SCL), U3.6 (SCL), U4.6 (P7_SCL_D5)
/I2C_SDA: J8.6, R5.1, U1.1 (SDA), U2.1 (SDA), U3.5 (SDA), U4.5 (P6_SDA_D4)
/LED_ENABLE: R1.2, U4.1 (P26_A0_D0)
/LED_FAILURE: R3.2, U4.3 (P28_A2_D2)
/LED_GUARD: R4.2, U4.4 (P29_A3_D3)
/LED_OK: R2.2, U4.2 (P27_A1_D1)
/inject_T_limit: J2.24, R10.1, U1.3 (O.S.), U2.3 (O.S.), U4.9 (P2_D8_SCK)
/inject_eeprom_disconnect: D12.2 (A), J2.20, R9.2, U3.3 (E2)
/inject_tguard_disconnect: D11.2 (A), J2.16, R8.2, U2.5 (A2)
/inject_tref_disconnect: D10.2 (A), J2.12, R7.2, U1.5 (A2)
/watchdog_disable: J2.8, U4.10 (P4_D9_MISO)
GND: D1.1 (K), D2.1 (K), D3.1 (K), D4.1 (K), J2.1, J2.2, J2.5, J2.9, J2.13, J2.17, J2.21, J2.22, R7.1, R8.1, R9.1, R11.1, R12.1, R13.1, U1.4 (GND), U1.6 (A1), U2.4 (GND), U2.6 (A1), U2.7 (A0), U3.1 (E0), U3.2 (E1), U3.4 (VSS), U3.7 (~WC), U4.13 (GND)
unnamed: D1.2 (A), R2.1
unnamed: D2.2 (A), R3.1
unnamed: D3.2 (A), R4.1
unnamed: D4.2 (A), R1.1
unnamed: D10.1 (K), R11.2
unnamed: D11.1 (K), R12.2
unnamed: D12.1 (K), R13.2
unnamed: J2.6, J2.10, J2.14, J2.18, J2.23

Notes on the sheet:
Tooling Holes
Pull low to allow CPU flashing
Status
Test Connector
EEPROM
pico_infra: relais
Tguard
fortification
Address: 0x50 0x54 (disconnect)
RP2040
Tref
GPIO_PROBE_4 (uart tx)
Jumper: I2c controller simulator
GPIO_PROBE_5 (uart rx)
pico_infra: gpio
3V3 tentacle
Address: 0x48 0x4C (disconnect)
Address: 0x49 0x4D (disconnect)
pico_probe

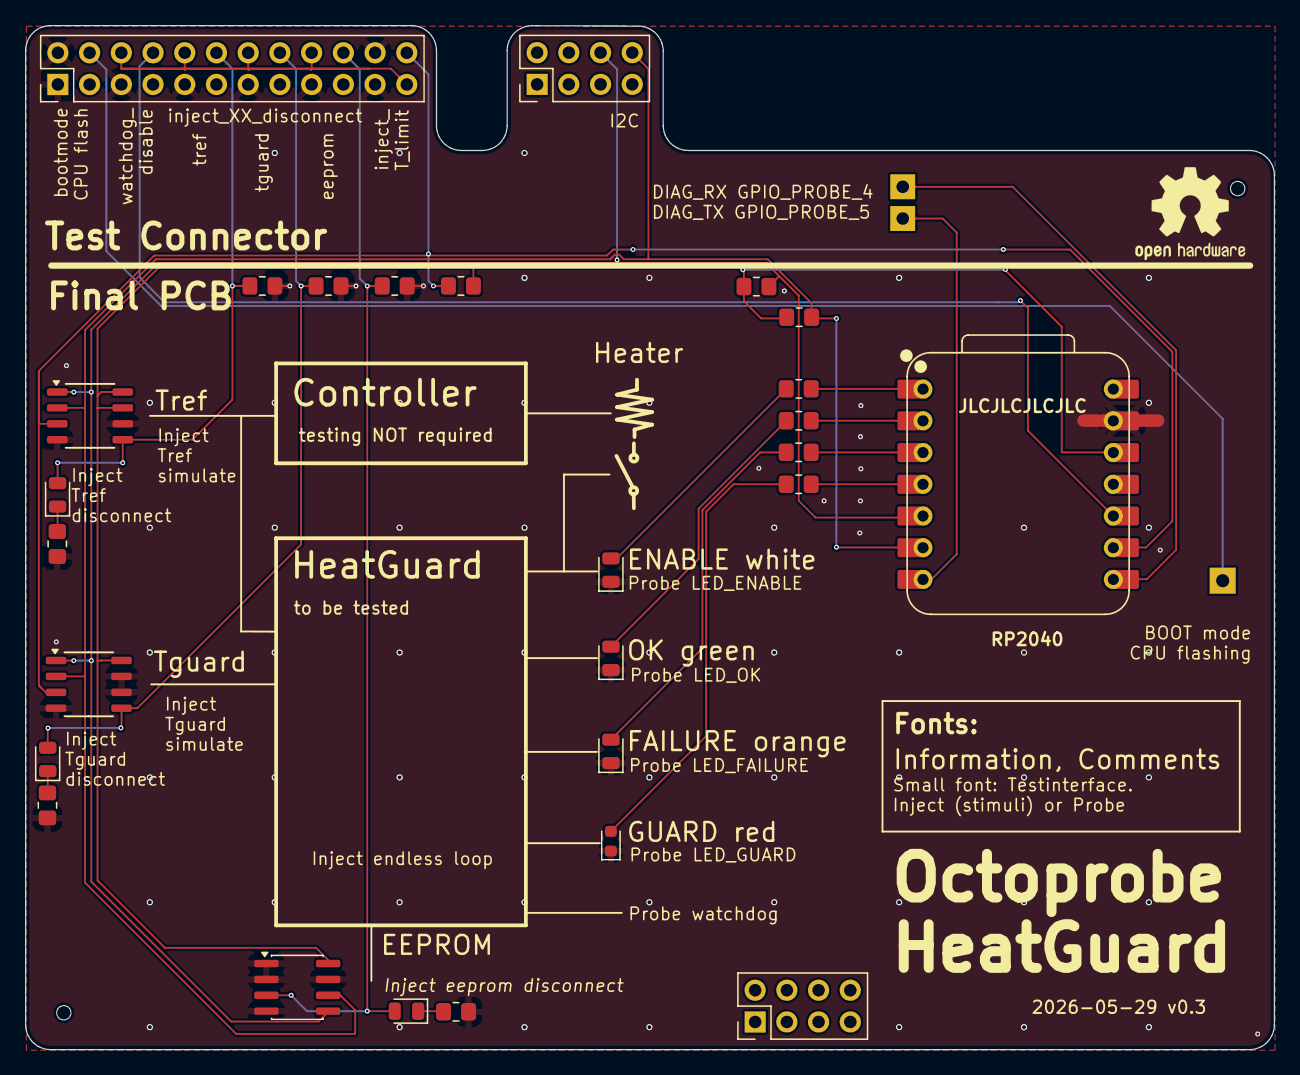
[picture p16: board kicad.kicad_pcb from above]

Board: 2 copper layers, 100.0 x 82.0 mm, 32 parts (0 on the bottom side), 24 nets.

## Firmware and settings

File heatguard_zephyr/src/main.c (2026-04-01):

/*
 * heatguard – Zephyr C port of the MicroPython heatguard application.
 *
 * Target: Raspberry Pi Pico (RP2040) / XIAO RP2040
 *
 * Peripherals
 *   UART0  115200 baud GPIO0/1  – diagnostic / stimulus interface
 *   I2C1   400 kHz    GPIO6/7  – LM75B temperature sensors + EEPROM
 *   GPIO26-29                  – status LEDs (enable / ok / failure / guard)
 *   GPIO16,17,25               – XIAO onboard LEDs (active-low)
 *   WDT                        – 3 s hardware watchdog
 */

#include <zephyr/kernel.h>
#include <zephyr/device.h>
#include <zephyr/devicetree.h>
#include <zephyr/drivers/gpio.h>
#include <zephyr/drivers/i2c.h>
#include <zephyr/drivers/uart.h>
#include <zephyr/drivers/watchdog.h>
#include <zephyr/drivers/hwinfo.h>
#include <hardware/structs/watchdog.h>

#include <math.h>
#include <stdio.h>
#include <stdlib.h>
#include <string.h>

/* ---------- constants ---------------------------------------------------- */

#define I2C_ADDRESS_TGUARD 0x48
#define I2C_ADDRESS_TREF   0x49
#define I2C_ADDRESS_EEPROM 0x50

#define TEMP_REG 0x00

#define EEPROM_START_BYTE 0x00
#define EEPROM_SIZE_BYTE  0x200
#define EEPROM_PAGE_SIZE  16

#define GUARD_RECOVERY_MS 60000
#define WATCHDOG_TIMEOUT_MS 3000

/* GPIO pin numbers (accent on gpio0 bank) */
#define LED_ENABLE_PIN     26
#define LED_OK_PIN         27
#define LED_FAILURE_PIN    28
#define LED_GUARD_PIN      29
#define LED_XIAO_GREEN_PIN 16 /* active-low */
#define LED_XIAO_RED_PIN   17 /* active-low */
#define LED_XIAO_BLUE_PIN  25 /* active-low */

/* ---------- state machine ------------------------------------------------ */

enum heatguard_state {
	STATE_INIT,
	STATE_OK,
	STATE_FAILURE,
	STATE_GUARD,
};

static const char *state_names[] = {
	[STATE_INIT]    = "INIT",
	[STATE_OK]      = "OK",
	[STATE_FAILURE] = "FAILURE",
	[STATE_GUARD]   = "GUARD",
};

/* ---------- devices ------------------------------------------------------ */

static const struct device *gpio0_dev;
static const struct device *i2c1_dev;
static const struct device *uart0_dev;
static const struct device *wdt_dev;
static int wdt_channel_id = -1;

/* ---------- heatguard state ---------------------------------------------- */

static struct {
	enum heatguard_state state;
	bool enable;
	enum heatguard_state before_state;
	bool before_enable;
	char last_reason[128];
	int64_t guard_end_ms;
} hg;

/* ---------- UART RX buffer ----------------------------------------------- */

#define UART_BUF_SIZE 256
static char uart_rx_buf[UART_BUF_SIZE];
static int  uart_rx_pos;

/* ========================================================================= */
/*  Boot cause                                                               */
/* ========================================================================= */

static const char *get_boot_cause(void)
{
	/*
	 * The Zephyr hwinfo driver for RP2040 does not map watchdog resets
	 * to RESET_WATCHDOG (only RP2350 does).  On RP2040 a WDT reset
	 * triggers a PSM restart which the driver reports as RESET_DEBUG.
	 *
	 * Use the RP2040 watchdog reason register directly: bit 0 (TIMER)
	 * is set after a watchdog timeout, bit 1 (FORCE) after a forced reset.
	 */
	if (watchdog_hw->reason & (WATCHDOG_REASON_TIMER_BITS |
				   WATCHDOG_REASON_FORCE_BITS)) {
		return "WDT_RESET";
	}

	uint32_t cause;

	if (hwinfo_get_reset_cause(&cause) < 0) {
		return "UNKNOWN";
	}

	if (cause & RESET_POR) {
		return "PWRON_RESET";
	}
	return "UNKNOWN";
}

/* ========================================================================= */
/*  Watchdog                                                                 */
/* ========================================================================= */

static int watchdog_start(void)
{
	struct wdt_timeout_cfg cfg = {
		.window.min = 0,
		.window.max = WATCHDOG_TIMEOUT_MS,
		.callback   = NULL,
		.flags      = WDT_FLAG_RESET_SOC,
	};

	wdt_dev = DEVICE_DT_GET(DT_NODELABEL(wdt0));
	if (!device_is_ready(wdt_dev)) {
		printk("Watchdog device not ready\n");
		return -1;
	}

	wdt_channel_id = wdt_install_timeout(wdt_dev, &cfg);
	if (wdt_channel_id < 0) {
		printk("Watchdog install failed: %d\n", wdt_channel_id);
		return wdt_channel_id;
	}

	return wdt_setup(wdt_dev, WDT_OPT_PAUSE_HALTED_BY_DBG);
}

static void watchdog_feed(void)
{
	if (wdt_channel_id >= 0) {
		wdt_feed(wdt_dev, wdt_channel_id);
	}
}

/* ========================================================================= */
/*  LEDs                                                                     */
/* ========================================================================= */

static void leds_init(void)
{
	gpio0_dev = DEVICE_DT_GET(DT_NODELABEL(gpio0));
	if (!device_is_ready(gpio0_dev)) {
		printk("GPIO0 device not ready\n");
		return;
	}

	gpio_pin_configure(gpio0_dev, LED_ENABLE_PIN,     GPIO_OUTPUT_INACTIVE);
	gpio_pin_configure(gpio0_dev, LED_OK_PIN,         GPIO_OUTPUT_INACTIVE);
	gpio_pin_configure(gpio0_dev, LED_FAILURE_PIN,    GPIO_OUTPUT_INACTIVE);
	gpio_pin_configure(gpio0_dev, LED_GUARD_PIN,      GPIO_OUTPUT_INACTIVE);
	/* XIAO onboard LEDs are active-low → start OFF (pin high) */
	gpio_pin_configure(gpio0_dev, LED_XIAO_GREEN_PIN, GPIO_OUTPUT_ACTIVE);
	gpio_pin_configure(gpio0_dev, LED_XIAO_RED_PIN,   GPIO_OUTPUT_ACTIVE);
	gpio_pin_configure(gpio0_dev, LED_XIAO_BLUE_PIN,  GPIO_OUTPUT_ACTIVE);
}

static void leds_set_all(bool on)
{
	int v = on ? 1 : 0;

	gpio_pin_set(gpio0_dev, LED_ENABLE_PIN,  v);
	gpio_pin_set(gpio0_dev, LED_OK_PIN,      v);
	gpio_pin_set(gpio0_dev, LED_FAILURE_PIN, v);
	gpio_pin_set(gpio0_dev, LED_GUARD_PIN,   v);
}

/* ========================================================================= */
/*  UART diagnostics                                                         */
/* ========================================================================= */

static void diag_init(void)
{
	uart0_dev = DEVICE_DT_GET(DT_NODELABEL(uart0));
	if (!device_is_ready(uart0_dev)) {
		printk("UART0 device not ready\n");
	}
	uart_rx_pos = 0;
}

static void diag_writeline(const char *line)
{
	while (*line) {
		uart_poll_out(uart0_dev, *line++);
	}
	uart_poll_out(uart0_dev, '\n');
}

static bool diag_readline(char *buf, size_t buf_size)
{
	unsigned char c;

	while (uart_poll_in(uart0_dev, &c) == 0) {
		if (c == '\n' || c == '\r') {
			if (uart_rx_pos > 0) {
				uart_rx_buf[uart_rx_pos] = '\0';
				strncpy(buf, uart_rx_buf, buf_size - 1);
				buf[buf_size - 1] = '\0';
				uart_rx_pos = 0;
				return true;
			}
		} else if (uart_rx_pos < UART_BUF_SIZE - 1) {
			uart_rx_buf[uart_rx_pos++] = (char)c;
		}
	}
	return false;
}

/* ========================================================================= */
/*  I2C helpers                                                              */
/* ========================================================================= */

static void i2c_bus_init(void)
{
	i2c1_dev = DEVICE_DT_GET(DT_NODELABEL(i2c1));
	if (!device_is_ready(i2c1_dev)) {
		printk("I2C1 device not ready\n");
	}
}

static int i2c_read_temperature(uint8_t addr, float *temp_out)
{
	uint8_t reg = TEMP_REG;
	uint8_t data[2];
	int ret;

	ret = i2c_write_read(i2c1_dev, addr, &reg, 1, data, 2);
	if (ret < 0) {
		return ret;
	}

	/* LM75B: 11-bit two's-complement, upper 11 bits of 16-bit register */
	int raw = ((data[0] << 8) | data[1]) >> 5;

	if (raw & 0x400) {
		raw -= 0x800;
	}

	*temp_out = raw * 0.125f;
	return 0;
}

static int i2c_read_eeprom(uint8_t addr, char *buf, size_t buf_size)
{
	uint8_t reg = EEPROM_START_BYTE;
	uint8_t data[EEPROM_SIZE_BYTE];
	int ret;

	ret = i2c_write_read(i2c1_dev, addr, &reg, 1, data, sizeof(data));
	if (ret < 0) {
		return ret;
	}

	/* Trim at first 0xFF byte */
	size_t len = sizeof(data);

	for (size_t i = 0; i < sizeof(data); i++) {
		if (data[i] == 0xFF) {
			len = i;
			break;
		}
	}

	if (len >= buf_size) {
		len = buf_size - 1;
	}
	memcpy(buf, data, len);
	buf[len] = '\0';
	return 0;
}

static int i2c_write_eeprom(uint8_t addr, const char *str)
{
	size_t total  = strlen(str);
	size_t offset = 0;

	while (offset < total) {
		size_t chunk = total - offset;

		if (chunk > EEPROM_PAGE_SIZE) {
			chunk = EEPROM_PAGE_SIZE;
		}

		uint8_t buf[EEPROM_PAGE_SIZE + 1];

		buf[0] = (uint8_t)(EEPROM_START_BYTE + offset);
		memcpy(&buf[1], &str[offset], chunk);

		int ret = i2c_write(i2c1_dev, buf, chunk + 1, addr);

		if (ret < 0) {
			return ret;
		}

		k_msleep(5); /* EEPROM write-cycle time */
		offset += EEPROM_PAGE_SIZE;
	}
	return 0;
}

/* ========================================================================= */
/*  HeatGuard state machine                                                  */
/* ========================================================================= */

static void guard_end_reset(void)
{
	hg.guard_end_ms = k_uptime_get() + GUARD_RECOVERY_MS;
}

static int64_t guard_remaining_ms(void)
{
	return hg.guard_end_ms - k_uptime_get();
}

static void write_state(const char *reason)
{
	char msg[256];

	snprintf(msg, sizeof(msg), "probe state %s %s '%s'",
		 state_names[hg.state], hg.enable ? "True" : "False", reason);
	diag_writeline(msg);
}

static void heatguard_init(void)
{
	hg.state        = STATE_INIT;
	hg.enable       = false;
	hg.before_state = STATE_INIT;
	hg.before_enable = false;
	strncpy(hg.last_reason, "Initial state after power up",
		sizeof(hg.last_reason));
	hg.guard_end_ms = k_uptime_get();
}

static void heatguard_update(void)
{
	if (hg.state == STATE_INIT) {
		hg.state = STATE_OK;
	}
	if (hg.state == STATE_GUARD && guard_remaining_ms() < 0) {
		hg.state = STATE_OK;
	}

	hg.enable = (hg.state == STATE_OK);

	gpio_pin_set(gpio0_dev, LED_ENABLE_PIN,  hg.enable);
	gpio_pin_set(gpio0_dev, LED_OK_PIN,      hg.state == STATE_OK);
	gpio_pin_set(gpio0_dev, LED_FAILURE_PIN, hg.state == STATE_FAILURE);
	gpio_pin_set(gpio0_dev, LED_GUARD_PIN,   hg.state == STATE_GUARD);

	if (hg.enable != hg.before_enable || hg.state != hg.before_state) {
		hg.before_enable = hg.enable;
		hg.before_state  = hg.state;
		write_state(hg.last_reason);
		hg.last_reason[0] = '\0';

		if (hg.state == STATE_GUARD) {
			i2c_write_eeprom(I2C_ADDRESS_EEPROM,
					 "{'state': 'GUARD'}");
		}
	}
}

static void heatguard_sensor_failed(const char *sensor)
{
	guard_end_reset();

	if (hg.state == STATE_INIT || hg.state == STATE_GUARD) {
		return;
	}

	snprintf(hg.last_reason, sizeof(hg.last_reason),
		 "I2C failed for sensor %s!", sensor);
	hg.state = STATE_FAILURE;
}

static void heatguard_update_temperatures(float t_guard, float diff)
{
	if (hg.state == STATE_INIT || hg.state == STATE_GUARD) {
		return;
	}

	if (t_guard >= 80.0f) {
		guard_end_reset();
		if (hg.state == STATE_OK || hg.state == STATE_FAILURE) {
			snprintf(hg.last_reason, sizeof(hg.last_reason),
				 "Too hot! Activate guard: "
				 "temperature_Tguard_C=%.3fC",
				 (double)t_guard);
			hg.state = STATE_GUARD;
			return;
		}
	}

	if (diff >= 3.0f) {
		snprintf(hg.last_reason, sizeof(hg.last_reason),
			 "Temperature difference too high: diff_C=%.3fC",
			 (double)diff);
		hg.state = STATE_FAILURE;
		return;
	}

	hg.last_reason[0] = '\0';
	hg.state = STATE_OK;
}

/* ========================================================================= */
/*  Diagnostic command handler                                               */
/* ========================================================================= */

static void handle_diag_line(const char *line)
{
	float tguard, diff;

	if (sscanf(line,
		   "stimulus heatguard.update_temperatures("
		   "temperature_Tguard_C=%f, diff_C=%f)",
		   &tguard, &diff) == 2) {
		heatguard_update_temperatures(tguard, diff);
		heatguard_update();
		return;
	}

	if (strncmp(line, "stimulus heatguard.sensor_failed(", 33) == 0) {
		char sensor[32] = {0};

		if (sscanf(line,
			   "stimulus heatguard.sensor_failed(\"%31[^\"]\")",
			   sensor) == 1) {
			heatguard_sensor_failed(sensor);
			heatguard_update();
		}
		return;
	}

	if (strcmp(line, "inject timeover") == 0) {
		hg.guard_end_ms = k_uptime_get();
		heatguard_update();
		return;
	}

	if (strcmp(line, "inject endless_loop") == 0) {
		/* Deliberate infinite loop – the watchdog will reset the MCU */
		for (;;) {
		}
	}

	if (strcmp(line, "ping") == 0) {
		diag_writeline("pong 'response to ping'");
		return;
	}

	printk("diag line not recognised: %s\n", line);
}

static void handle_diag(void)
{
	char buf[UART_BUF_SIZE];

	if (diag_readline(buf, sizeof(buf))) {
		handle_diag_line(buf);
	}
}

/* ========================================================================= */
/*  main                                                                     */
/* ========================================================================= */

int main(void)
{
	printk("main()\n");

	leds_init();
	diag_init();
	i2c_bus_init();
	heatguard_init();
	watchdog_start();

	/* Brief flash of all status LEDs */
	leds_set_all(true);
	k_msleep(10);
	leds_set_all(false);

	char boot_msg[64];

	snprintf(boot_msg, sizeof(boot_msg), "probe boot %s",
		 get_boot_cause());
	diag_writeline(boot_msg);

	while (1) {
		handle_diag();
		heatguard_update();

		watchdog_feed();
		k_msleep(1000);
		watchdog_feed();

		gpio_pin_toggle(gpio0_dev, LED_XIAO_BLUE_PIN);

		float t_guard, t_ref;
		char eeprom_buf[EEPROM_SIZE_BYTE + 1];

		if (i2c_read_temperature(I2C_ADDRESS_TGUARD, &t_guard) < 0) {
			heatguard_sensor_failed("Tguard");
			heatguard_update();
			continue;
		}
		if (i2c_read_temperature(I2C_ADDRESS_TREF, &t_ref) < 0) {
			heatguard_sensor_failed("Tref");
			heatguard_update();
			continue;
		}
		if (i2c_read_eeprom(I2C_ADDRESS_EEPROM,
				    eeprom_buf, sizeof(eeprom_buf)) < 0) {
			heatguard_sensor_failed("eeprom");
			heatguard_update();
			continue;
		}

		float diff = fabsf(t_guard - t_ref);
		int64_t remaining = guard_remaining_ms();

		if (remaining < -1) {
			remaining = -1;
		}

		char telemetry[256];

		snprintf(telemetry, sizeof(telemetry),
			 "Tguard=%.3fC Tref=%.3fC diff=%.3f "
			 "state=%s enable=%d guard_remaining_ms=%lld",
			 (double)t_guard, (double)t_ref, (double)diff,
			 state_names[hg.state], hg.enable,
			 (long long)remaining);
		diag_writeline(telemetry);

		heatguard_update_temperatures(t_guard, diff);
	}

	return 0;
}

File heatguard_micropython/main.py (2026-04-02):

"""
This is the micropython implementation of 'heatguard'.
"""

import errno
import time

import machine  # type: ignore
import micropython  # type: ignore
import rp2  # type: ignore

# ab
micropython.alloc_emergency_exception_buf(100)

I2C_ADDRESS_Tguard = 0x48
I2C_ADDRESS_Tref = 0x49
I2C_ADDRESS_EEPROM = 0x50
I2C_ADDRESS_OFFSET_DISCONNECT = 4

BOOT_CAUSE = {
    machine.PWRON_RESET: "PWRON_RESET",
    machine.WDT_RESET: "WDT_RESET",
}.get(machine.reset_cause(), "UNKNOWN")


def print_error(error_text: str) -> None:
    assert isinstance(error_text, str)
    print("[ERROR]" + repr(error_text))


class Watchdog:
    TIMEOUT_MS = 3_000

    def __init__(self) -> None:
        self.wdt: machine.WDT | None = None

    def start(self) -> None:
        self.wdt = machine.WDT(timeout=self.TIMEOUT_MS)

    def feed(self) -> None:
        if self.wdt is None:
            return

        self.wdt.feed()

    @staticmethod
    def stop() -> None:
        """
        The watchdog should never be stopped.
        However, when starting a debug session, the watchdog is unwanted.
        """

        WATCHDOG_CTRL = 0x40058000
        "Address for the Watchdog Control Register"

        current_val = machine.mem32[WATCHDOG_CTRL]
        # Use a bitmask to clear bit 30 (the ENABLE bit)
        # 0x3FFFFFFF is a mask where all bits are 1 except bit 30
        machine.mem32[WATCHDOG_CTRL] = current_val & 0x3FFFFFFF


class Leds:
    def __init__(self) -> None:
        self.enable = machine.Pin("GPIO26", machine.Pin.OUT)
        self.ok = machine.Pin("GPIO27", machine.Pin.OUT)
        self.failure = machine.Pin("GPIO28", machine.Pin.OUT)
        self.guard = machine.Pin("GPIO29", machine.Pin.OUT)
        self.all = (self.enable, self.ok, self.failure, self.guard)
        # XIAO RP2040 onboard green LED (active LOW: 0=on, 1=off)
        self.xiao_inverse_green = machine.Pin("GPIO16", machine.Pin.OUT, value=1)
        self.xiao_inverse_red = machine.Pin("GPIO17", machine.Pin.OUT, value=1)
        self.xiao_inverse_blue = machine.Pin("GPIO25", machine.Pin.OUT, value=1)

    def set_all(self, on: bool = True) -> None:
        for pin in self.all:
            pin.value(on)

    def blink_leds(self) -> None:
        for pin in self.all:
            pin.value(1)
            time.sleep(0.2)
            pin.value(0)


class Diag:
    def __init__(self) -> None:
        self._uart = machine.UART(
            0,
            baudrate=115200,
            tx=machine.Pin("GPIO0"),
            rx=machine.Pin("GPIO1"),
            timeout=100,
        )

    def readline(self) -> str | None:
        if self._uart.any() == 0:
            return None
        line = self._uart.readline()
        assert isinstance(line, bytes)
        return line.decode("utf-8", "replace").strip()

    def writeline(self, line: str) -> None:
        self._uart.write(line + "\n")

    def ping_forever(self) -> None:
        for i in range(1_000_000):
            msg = f"ping {i}"
            print(msg)
            self.writeline(msg)
            time.sleep(1.0)


class I2C:
    TEMP_REG = 0x00
    "Temperature register address"

    def __init__(self) -> None:
        pin_sda = machine.Pin("GPIO6")
        pin_scl = machine.Pin("GPIO7")
        self._i2c = machine.I2C(1, sda=pin_sda, scl=pin_scl, freq=400_000)

    def scan_i2c(self) -> list[int]:
        """
        Scan for I2C devices
        """
        print("Scanning I2C bus...")
        devices = self._i2c.scan()
        assert isinstance(devices, list)

        if len(devices) == 0:
            print("No I2C devices found!")
        else:
            print(f"Found {len(devices)} device(s):")
            for device in devices:
                print(f"  - 0x{device:02x}")

        return devices

    def read_temperature(self, addr: int) -> float:
        """
        Read temperature from LM75B sensor.
        Throw an exception if failed.
        """
        # Read 2 bytes from temperature register
        data = self._i2c.readfrom_mem(addr, self.TEMP_REG, 2)
        assert isinstance(data, bytes)

        # Convert to temperature (11-bit resolution)
        # Combine the two bytes and shift right by 5 bits
        temp_raw = (data[0] << 8 | data[1]) >> 5

        # Check if negative (bit 10 is sign bit)
        if temp_raw & 0x400:
            temp_raw = temp_raw - 0x800

        # Convert to Celsius (0.125°C per LSB)
        temperature = temp_raw * 0.125

        return temperature

    def read_temperature_remote(self, addr: int) -> float:
        """
        Read temperature from LM75B sensor.
        If failed, write 'print_error()'.
        This is useful for mpremote calls.
        """
        try:
            return self.read_temperature(addr=addr)
        except OSError as e:
            if e.errno == errno.EIO:
                print_error("I2C_EIO")
                return 0.0
            raise

    def read_EEPROM(self, addr: int) -> str:
        """
        Throw an exception if failed.
        """
        # Read 2 bytes from temperature register
        EEPROM_START_BYTE = 0x00
        EEPROM_SIZE_BYTE = 0x200
        "2 Kbit = 0x800 bits = 0x200 bytes"
        data = self._i2c.readfrom_mem(addr, EEPROM_START_BYTE, EEPROM_SIZE_BYTE)
        assert isinstance(data, bytes)

        pos = data.find(b"\xff")
        if pos >= 0:
            data = data[0:pos]
        return data.decode("utf-8", "replace")

    def read_EEPROM_remote(self, addr: int) -> str:
        """
        If failed, write 'print_error()'.
        This is useful for mpremote calls.
        """
        try:
            return self.read_EEPROM(addr=addr)
        except OSError as e:
            if e.errno == errno.EIO:
                print_error("I2C_EIO")
                return ""
            raise

    def write_EEPROM(self, addr: int, data: str) -> None:
        """
        Write data string to EEPROM.
        Throw an exception if failed.
        """
        EEPROM_START_BYTE = 0x00
        PAGE_SIZE = 16
        encoded = data.encode("utf-8")
        offset = 0
        while offset < len(encoded):
            chunk = encoded[offset : offset + PAGE_SIZE]
            self._i2c.writeto_mem(addr, EEPROM_START_BYTE + offset, chunk)
            time.sleep(0.005)  # 5ms EEPROM write cycle
            offset += PAGE_SIZE
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

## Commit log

2026-02-24 Expand README with naming proposals and industry applications
    Added section with naming proposals for subsystems and applications across various industries, including technical, action, and modern options.
    [testbed_heatguard.kicad_pcb, testbed_heatguard.kicad_sch, testbed_heatguard_controller.kicad_sch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]
2026-02-24 v1.0 as ordered
    [Seeed-Studio-XIAO-RP2040-v26.step, bom.csv, designators.csv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]
2026-03-16 cp heatguard_v01 heatguard_v02
    [Seeed-Studio-XIAO-RP2040-v26.step, kicad.kicad_pcb, kicad.kicad_sch]
2026-03-16 v0.2: XIAO: Now smd (was on pins)
    [kicad.kicad_pcb, kicad.kicad_sch]
2026-03-16 v0.2 ready for review
    [kicad.kicad_pcb, kicad.kicad_sch]
2026-03-17 v0.2 beta
    [bom.csv, designators.csv, kicad.kicad_pcb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]
2026-03-17 Remove all vias
    [kicad.kicad_pcb]
2026-03-17 v0.2 as ordered
    [kicad.kicad_pcb, kicad.kicad_sch, positions.csv]
2026-03-24 Implement uart
2026-03-25 Update documentation
    [testbed_heatguard.kicad_pcb, testbed_heatguard.kicad_sch, testbed_heatguard_controller.kicad_sch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]
2026-03-26 Kicad Schematics A3 -> A4
    [kicad.kicad_sch]
2026-03-28 debugprobe: power on and get tty
2026-03-29 cli: heatguard
2026-03-31 Use uart of PICO_PROBE
    [kicad.kicad_sch]
2026-04-01 zephyr version now starts up correctly
    [main.c]
2026-04-02 heatguard dut-flash now flashes micropython AND zephyr!
2026-05-29 kicad copy v0.2 -> v0.3
    [Seeed-Studio-XIAO-RP2040-v26.step, bom.csv, designators.csv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]
2026-05-29 Changes v0.2 -> v0.3 A
    [kicad.kicad_pcb, kicad.kicad_sch]
2026-05-30 Changes v0.2 -> v0.3 B: PCB: XIAO rp2040: Replace SMD with THT
    [kicad.kicad_pcb, kicad.kicad_sch]
2026-05-30 Changes v0.2 -> v0.3 C: Use relays in favor of GPIO
    [kicad.kicad_pcb, kicad.kicad_sch]
2026-05-30 v0.3: production_v0.3
    [bom.csv, designators.csv, positions.csv]
2026-06-09 Migrated to PCB v0.3
2026-06-09 PCB stacking: Blue color. Update images with blue color
    [kicad.kicad_pcb]
2026-06-09 Update pin assignements

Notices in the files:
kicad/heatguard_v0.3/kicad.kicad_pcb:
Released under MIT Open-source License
